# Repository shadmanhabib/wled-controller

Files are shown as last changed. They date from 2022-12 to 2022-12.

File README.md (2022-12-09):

# WLED-Controller

## Table of Contents
- [Automated Fuel Card Processing](#automated-fuel-card-processing)
  - [Table of Contents](#table-of-contents)
  - [About The Project](#about-the-project)
  - [Getting Started](#getting-started)
    - [Prerequisites](#prerequisites)
    - [Installation](#installation)
  - [Usage](#usage)
  - [Changelog](#changelog)

## About The Project
PCB design and fabrication of ESP8266 based controller for WLED.

This project contains multiple branches, each with its own unique use case and form factor. This is the main branch which contains the smallest controller with the least number of additional features.

## Getting Started
To get a build this project (or parts thereof), these steps may be followed.

### Prerequisites
1. A download of either the WLED binary or source code that can be compile for upload onto the ESP8266.
2. If you want to make changes to the PCB design or would like to generate new fabrication files, an installation of KiCAD is required.

### Installation
1. Manufacture a PCB.
2. Upload WLED using ESPHomeFlasher or other programs.

## Usage
Examples will be given in future iterations of this file.

_For more examples, please refer to the [Documentation](https://)_

## Changelog
All notable changes to this project will be documented in this section.

The format is based on [Keep a Changelog](https://keepachangelog.com/en/1.0.0/),
and this project attempts to adhere to [Semantic Versioning](https://semver.org/spec/v2.0.0.html).

### [v2.0.0]
#### Changed
- New compact form factor.
- Multiple changes to component selection.
- Removed micro USB port. Replaced with 2.54mm pin header.

#### Added
- Power switching between LiPo and 5V external with external priority.

#### Removed
- Boost converter.

### [v1.0.0]
#### Initial design
- ESP8266 based design.
- Single-cell LiPo charge circuit.
- Boost converter for 5V output.
- Logic level converter (bi-directional 3.3-5V).

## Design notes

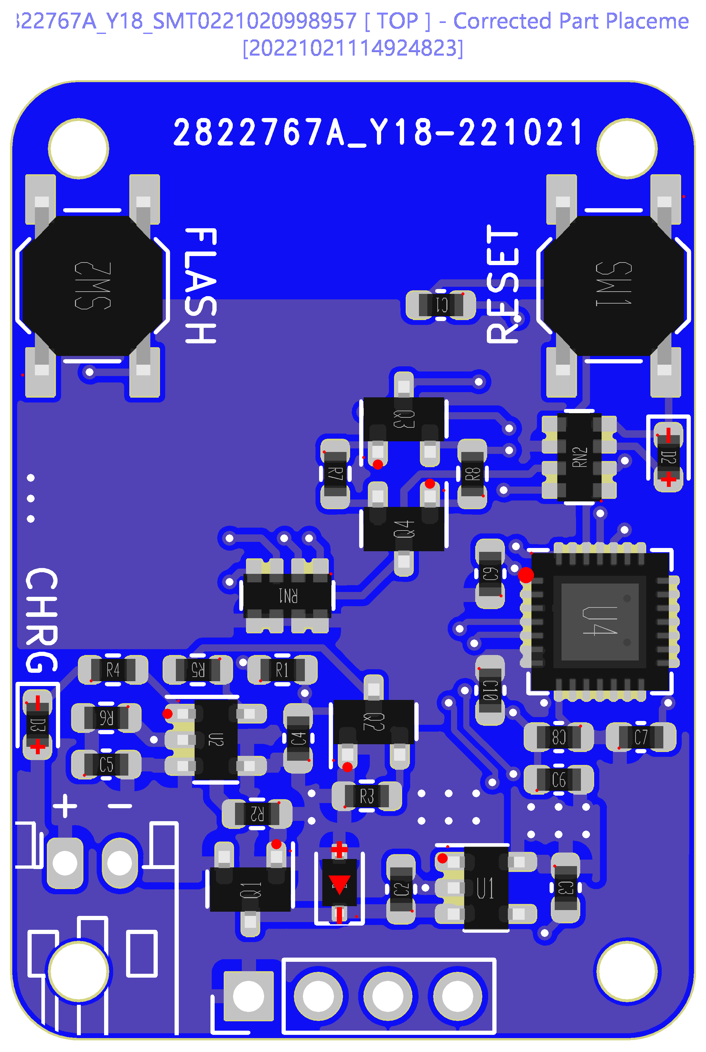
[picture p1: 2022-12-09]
hardware/documentation/Produce_DanZhi.SMT_Snapshot.Top.2822767A_Y18.SMT0221020998957.png

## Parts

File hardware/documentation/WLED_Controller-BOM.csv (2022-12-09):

Comment | Designator | Footprint | LCSC
0.1uF | C1,C6,C8,C10 | Capacitor_SMD:C_0603_1608Metric | C14663
1uF | C2,C3,C4,C5 | Capacitor_SMD:C_0603_1608Metric | C15849
10uF | C7,C9 | Capacitor_SMD:C_0603_1608Metric | C96446
1N5819 | D1 | Diode_SMD:D_SOD-323 | C191023
LED_blue | D2 | LED_SMD:LED_0603_1608Metric | C72041
LED_red | D3 | LED_SMD:LED_0603_1608Metric | C2286
AO3401A | Q1 | Package_TO_SOT_SMD:SOT-23 | C15127
AO3400A | Q2,Q3,Q4 | Package_TO_SOT_SMD:SOT-23 | C20917
10k | R1,R7,R8 | Resistor_SMD:R_0603_1608Metric | C25804
100k | R2,R3 | Resistor_SMD:R_0603_1608Metric | C25803
330 | R4 | Resistor_SMD:R_0603_1608Metric | C23138
2k | R5 | Resistor_SMD:R_0603_1608Metric | C17604
1 | R6 | Resistor_SMD:R_0603_1608Metric | C22936
10k | RN1 | Resistor_SMD:R_Array_Concave_4x0603 | C29718
470 | RN2 | Resistor_SMD:R_Array_Concave_4x0603 | C25510
SW_SPST | SW1,SW2 | Button_Switch_SMD:SW_SPST_TL3342 | C318884
AP2112K-3.3 | U1 | Package_TO_SOT_SMD:SOT-23-5 | C51118
LTC4054ES5-4.2 | U2 | Package_TO_SOT_SMD:TSOT-23-5 | C32574
ESP-12F | U3 | RF_Module:ESP-12E
CP2102N-Axx-xQFN28 | U4 | Package_DFN_QFN:QFN-28-1EP_5x5mm_P0.5mm_EP3.35x3.35mm | C6568

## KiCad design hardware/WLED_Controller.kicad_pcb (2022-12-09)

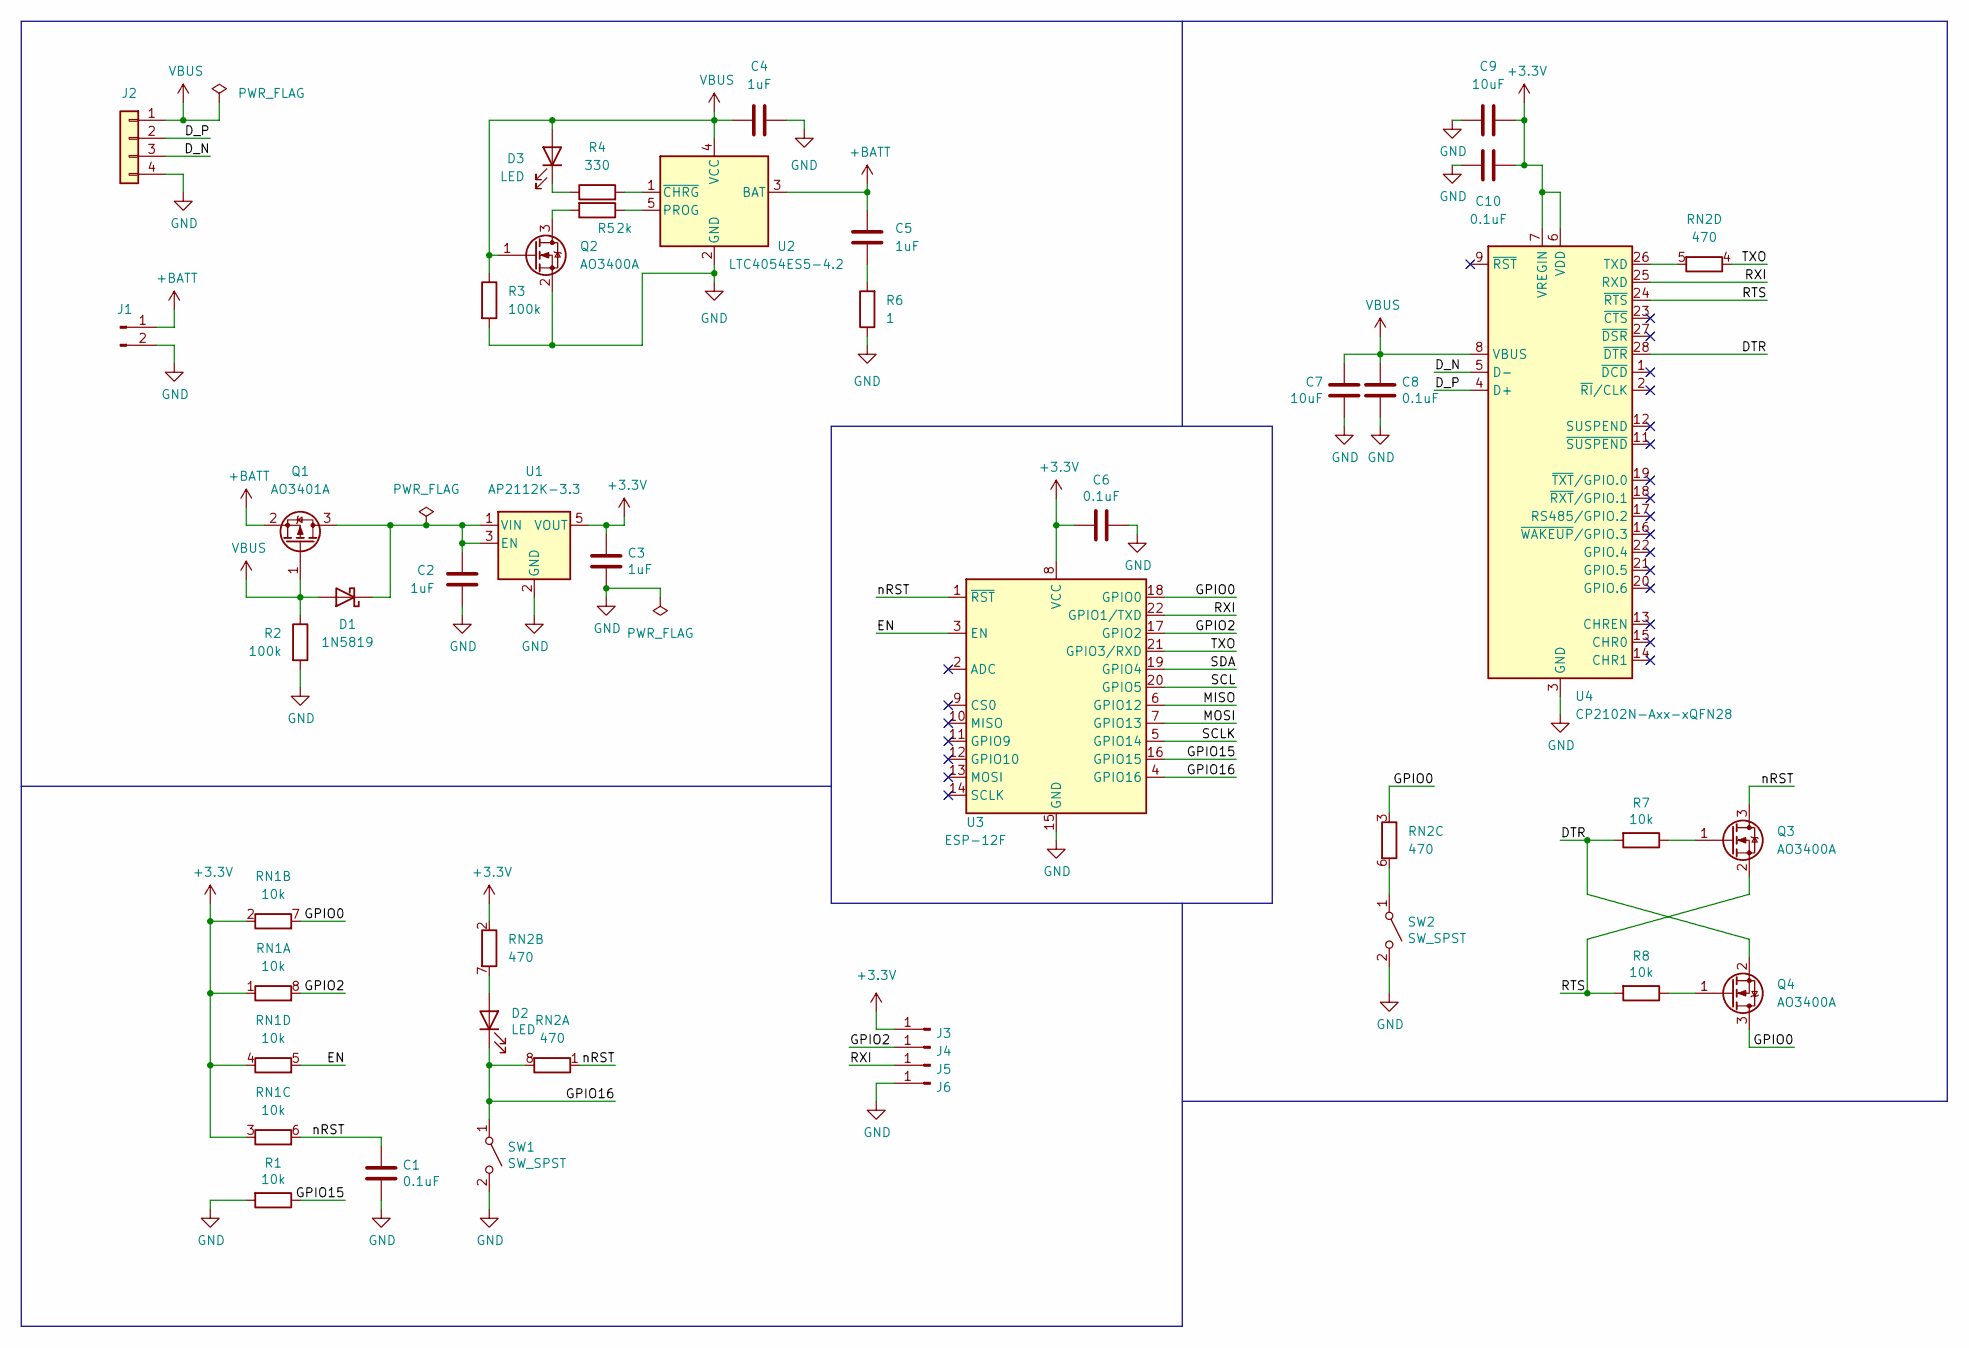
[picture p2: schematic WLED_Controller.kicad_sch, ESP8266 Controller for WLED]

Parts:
C1, C6, C8, C10: 0.1uF; C_0603_1608Metric
C2, C3, C4, C5: 1uF; C_0603_1608Metric
C7, C9: 10uF; C_0603_1608Metric
D1: 1N5819; D_SOD-323
D2, D3: LED; LED_0603_1608Metric
J1: Conn_01x02_Male; JST_PH_S2B-PH-K_1x02_P2.00mm_Horizontal
J2: Conn_01x04; PinHeader_1x04_P2.54mm_Vertical
J3, J4, J5, J6: Conn_01x01_Male; SolderWirePad_1x01_SMD_1x2mm
Q1: AO3401A; SOT-23
Q2, Q3, Q4: AO3400A; SOT-23
R1, R7, R8: 10k; R_0603_1608Metric
R2, R3: 100k; R_0603_1608Metric
R4: 330; R_0603_1608Metric
R5: 2k; R_0603_1608Metric
R6: 1; R_0603_1608Metric
RN1: 10k; R_Array_Convex_4x0603
RN2: 470; R_Array_Convex_4x0603
SW1, SW2: SW_SPST; SW_SPST_TL3342
U1: AP2112K-3.3; SOT-23-5
U2: LTC4054ES5-4.2; TSOT-23-5
U3: ESP-12F; ESP-12E
U4: CP2102N-Axx-xQFN28; QFN-28-1EP_5x5mm_P0.5mm_EP3.35x3.35mm

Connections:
+3V3: C3.1, C6.2, C9.1, C10.1, J3.1, RN1.1 (R1.1), RN1.2 (R2.1), RN1.3 (R3.1), RN1.4 (R4.1), RN2.2 (R2.1), U1.5 (VOUT), U3.8 (VCC), U4.6 (VDD), U4.7 (VREGIN)
+BATT: C5.2, J1.1, Q1.2 (S), U2.3 (BAT)
/DTR: Q4.2 (S), R7.2, U4.28 (~DTR)
/D_N: J2.3, U4.5 (D-)
/D_P: J2.2, U4.4 (D+)
/EN: RN1.5 (R4.2), U3.3 (EN)
/GPIO0: Q4.3 (D), RN1.7 (R2.2), RN2.3 (R3.1), U3.18 (GPIO0)
/GPIO2: J4.1, RN1.8 (R1.2), U3.17 (GPIO2)
/GPIO15: R1.1, U3.16 (GPIO15)
/GPIO16: D2.1 (K), RN2.8 (R1.2), SW1.1 (A), U3.4 (GPIO16)
/MISO: U3.6 (GPIO12)
/MOSI: U3.7 (GPIO13)
/RTS: Q3.2 (S), R8.2, U4.24 (~RTS)
/RXI: J5.1, U3.22 (GPIO1/TXD), U4.25 (RXD)
/SCL: U3.20 (GPIO5)
/SCLK: U3.5 (GPIO14)
/SDA: U3.19 (GPIO4)
/TXO: RN2.4 (R4.1), U3.21 (GPIO3/RXD)
/nRST: C1.1, Q3.3 (D), RN1.6 (R3.2), RN2.1 (R1.1), U3.1 (~RST)
GND: C1.2, C2.2, C3.2, C4.2, C6.1, C7.2, C8.2, C9.2, C10.2, J1.2, J2.4, J6.1, Q2.2 (S), R1.2, R2.2, R3.2, R6.1, SW1.2 (B), SW2.2 (B), U1.2 (GND), U2.2 (GND), U3.15 (GND), U4.3 (GND), U4.29 (GND)
unnamed: C2.1, D1.1 (K), Q1.3 (D), U1.1 (VIN), U1.3 (EN)
unnamed: C5.1, R6.2
unnamed: D2.2 (A), RN2.7 (R2.2)
unnamed: D3.1 (K), R4.1
unnamed: Q2.3 (D), R5.2
unnamed: Q3.1 (G), R7.1
unnamed: Q4.1 (G), R8.1
unnamed: R4.2, U2.1 (~CHRG)
unnamed: R5.1, U2.5 (PROG)
unnamed: RN2.5 (R4.2), U4.26 (TXD)
unnamed: RN2.6 (R3.2), SW2.1 (A)
VBUS: C4.1, C7.1, C8.1, D1.2 (A), D3.2 (A), J2.1, Q1.1 (G), Q2.1 (G), R2.1, R3.1, U2.4 (VCC), U4.8 (VBUS)

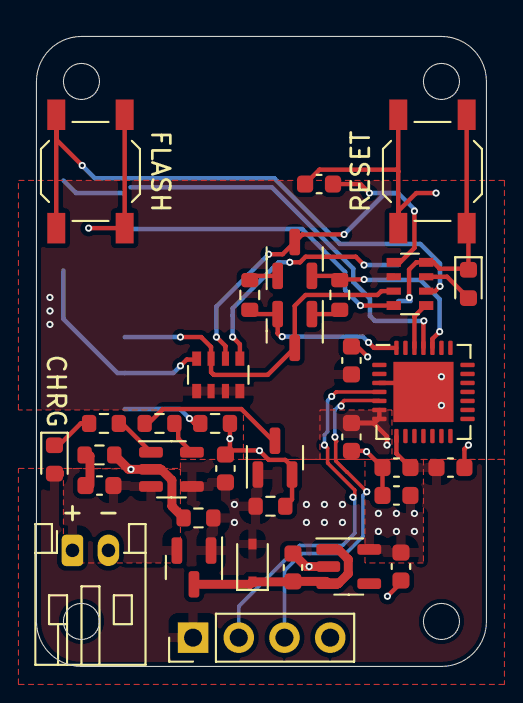
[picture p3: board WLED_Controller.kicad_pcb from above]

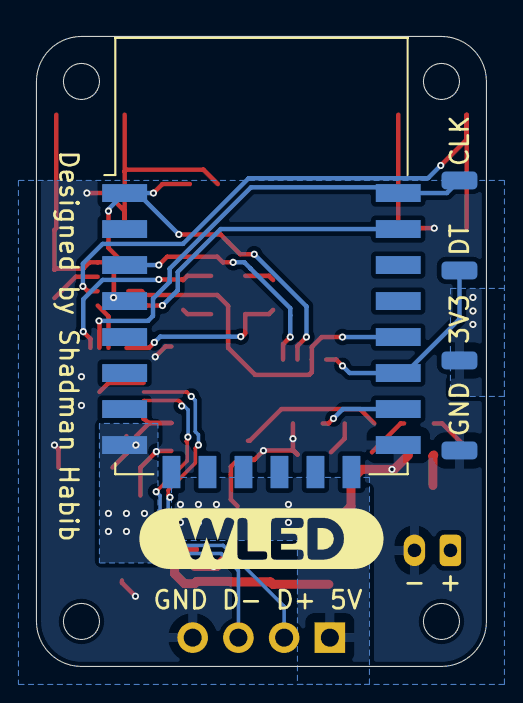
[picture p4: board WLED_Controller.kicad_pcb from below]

Board: 2 copper layers, 25.0 x 35.0 mm, 40 parts (6 on the bottom side), 27 nets.

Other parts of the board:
kibuzzard-6350B1D2: G***; kibuzzard-6350B1D2

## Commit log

2022-11-29 First commit
    The first commit contains all the files from v1.0.0 of the PCB design.
    [WLED_Controller-B_Cu.gbl, WLED_Controller-B_Mask.gbs, WLED_Controller-B_Paste.gbp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]
2022-11-29 Updated to v2.0.0
    Contains the PCB design and fabrication files for v2.0.0 of the WLED
    controller.
    [WLED_Controller-B_Cu.gbl, WLED_Controller-B_Mask.gbs, WLED_Controller-B_Paste.gbp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]
2022-12-09 Updated to v2.0.1
    Addition of PCB silkscreen and updates to project README.
    [WLED_Controller-BOM.csv, WLED_Controller.kicad_pcb, WLED_Controller.kicad_sch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]
